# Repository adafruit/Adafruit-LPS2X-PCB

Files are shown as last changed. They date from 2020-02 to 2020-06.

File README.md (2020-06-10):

## Adafruit LPS2X family of absolute pressure sensors PCB

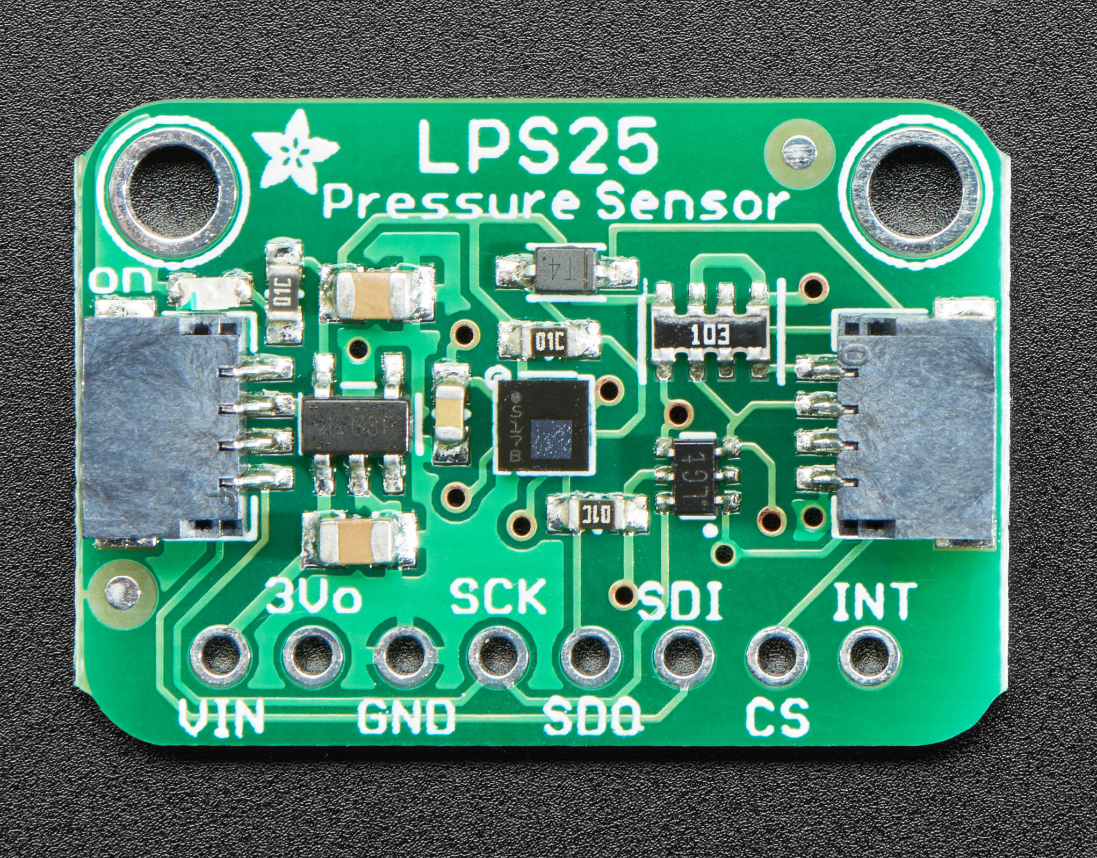
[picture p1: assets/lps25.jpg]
<a href="http://www.adafruit.com/products/4530">
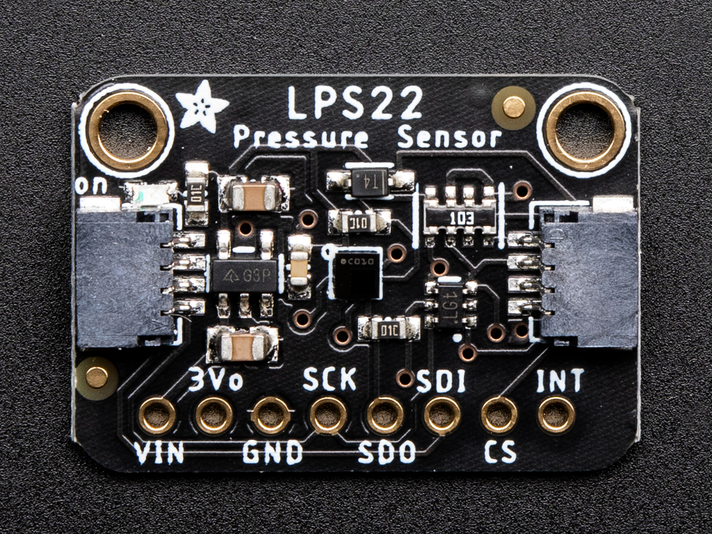
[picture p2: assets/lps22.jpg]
<a href="http://www.adafruit.com/products/4633">
  
Click here to purchase one from the Adafruit shop</a>

PCB files for the Adafruit LPS2X family of absolute pressure sensors. 

Format is EagleCAD schematic and board layout
* https://www.adafruit.com/product/4530
* http://www.adafruit.com/products/4633

### Description

We live on a planet with an atmosphere, a big ocean of gaseous air that keeps everything alive - and that atmosphere is constantly bouncing off of us, exerting air pressure on everything around us. But, how much air is in the atmosphere, bearing down on us?
Absolute pressure sensors  like the **ST LPS22HB** or **ST LPS25HB** can quickly and easily measure this air pressure, useful when you want to know about the weather (are we in a low pressure or high pressure system?) or to determine altitude, as the air thins out the higher we get above sea level. For example, at sea level, the official pressure level is **1013.25 hPa**. You can use these sensors to measure the current pressure where you are right now, to compare.

The LPS25 has a wide measurement range of **260-1260** hPa with 24-bit pressure data measurements that can be read up to **25 times a second (Hz)**, you can be confident that you always have an up to date and precise measurement. The LPS22 has the same measurement range but offers additional measurement rates of **50 and 75Hz**. They’re pretty dang accurate too, with the ability to measure within **0.2 hPa** after calibration (± 1 hPa before calibration).
### License

Adafruit invests time and resources providing this open source design, please support Adafruit and open-source hardware by purchasing products from [Adafruit](https://www.adafruit.com)!

Designed by Limor Fried/Ladyada for Adafruit Industries.

Creative Commons Attribution/Share-Alike, all text above must be included in any redistribution. 
See license.txt for additional details.

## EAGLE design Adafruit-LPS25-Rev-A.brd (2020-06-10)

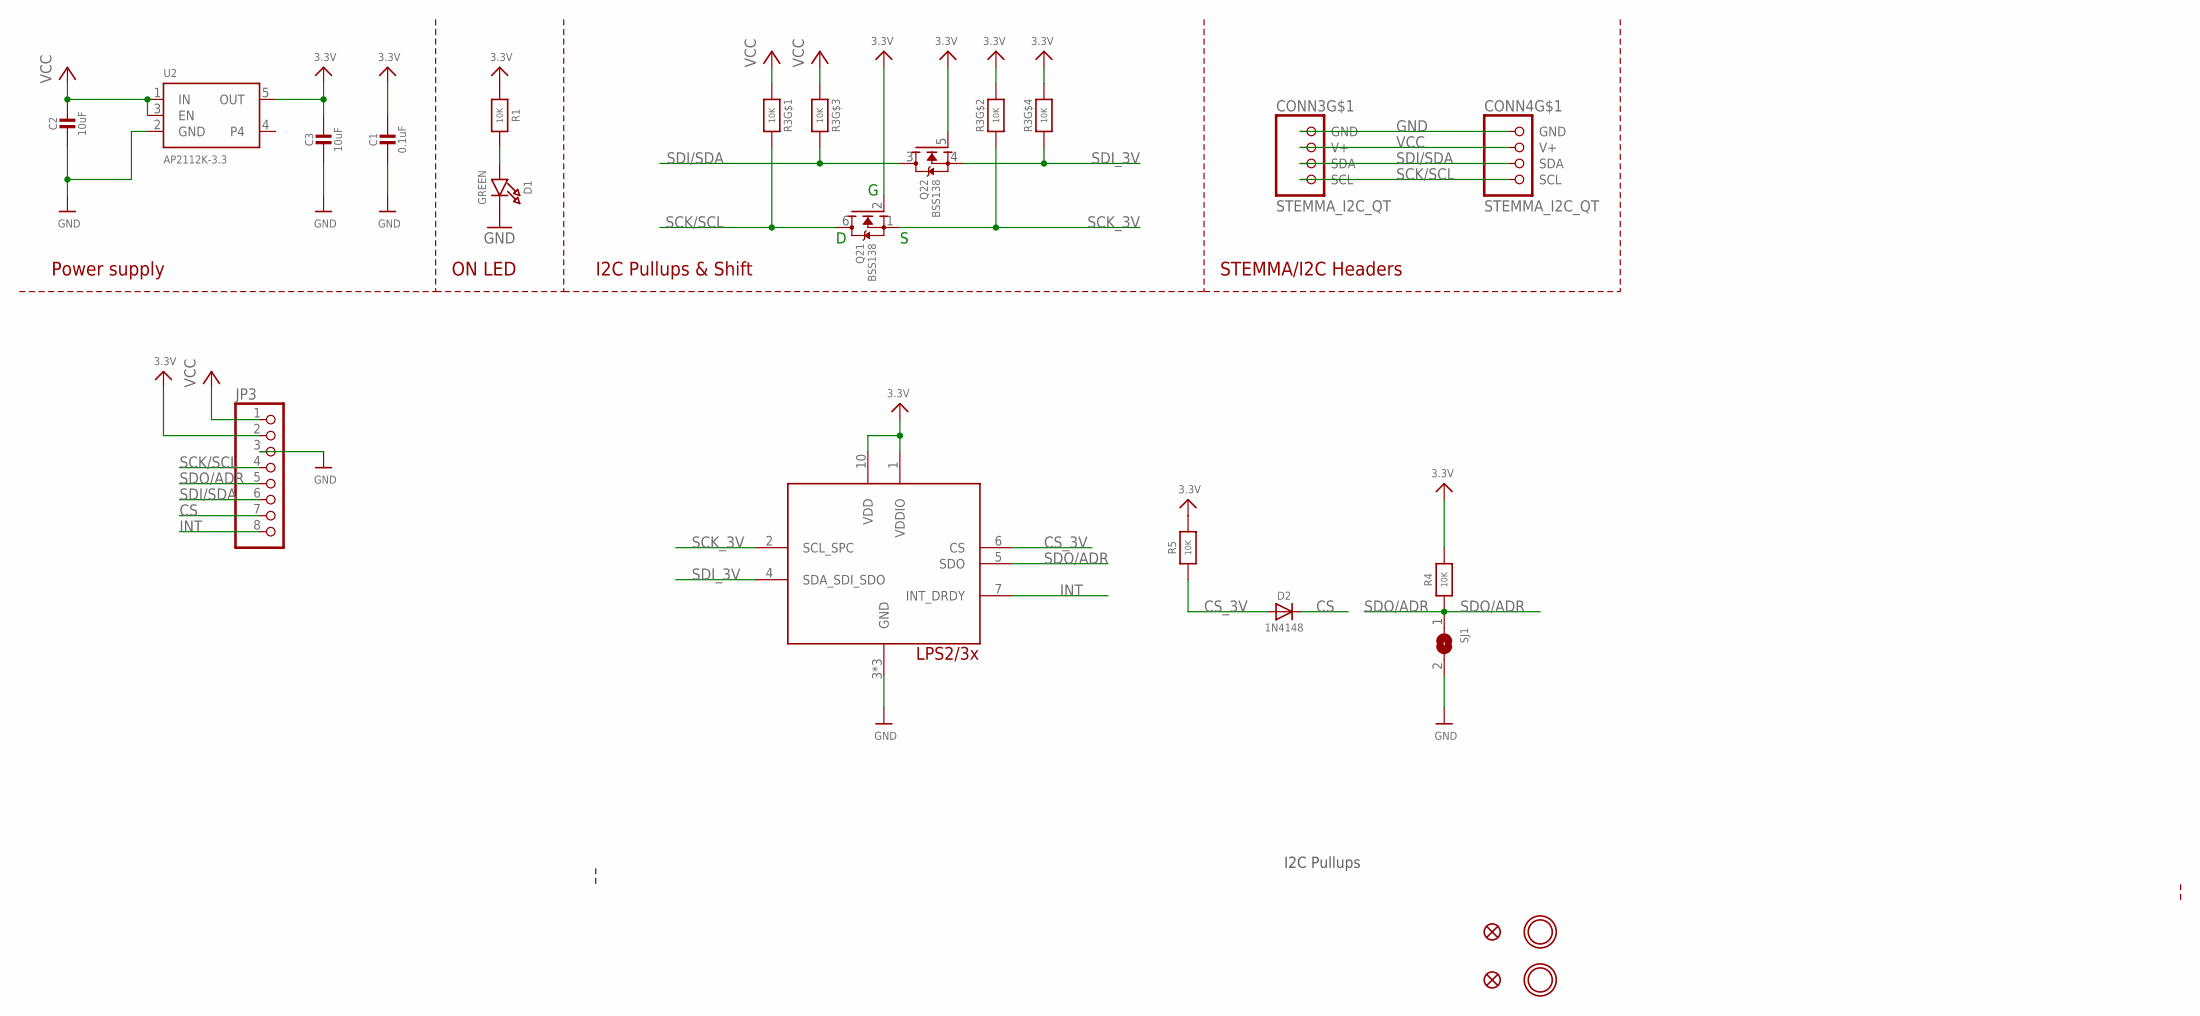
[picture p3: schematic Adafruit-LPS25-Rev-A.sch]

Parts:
C1: 0.1uF; 0603-NO
C2, C3: 10uF; 0805-NO
CONN3, CONN4: STEMMA_I2C_QT; JST_SH4
D1: GREEN; CHIPLED_0603_NOOUTLINE
D2: 1N4148; SOD-323
FID3, FID4: FIDUCIAL_1MM
JP3: HEADER-1X8ROUND; 1X08_ROUND
Q2: BSS138; SOT363
R1, R4, R5: 10K; 0603-NO
R3: 10K; RESPACK_4X0603
SJ1: SOLDERJUMPER; SOLDERJUMPER_ARROW_NOPASTE
U2: AP2112K-3.3; SOT23-5
U$1, U$17: MOUNTINGHOLE2.5; MOUNTINGHOLE_2.5_PLATED
U$2: LPS2X_LPS25; HLGA-10L

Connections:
3.3V: C1.1, C3.1, JP3.2, Q2.2 (G), Q2.5 (G), R1.1, R3.2 (1), R3.4 (1), R4.2, R5.2, U2.5 (OUT), U$2.1 (VDDIO), U$2.10 (VDD)
CS: D2.C, JP3.7
CS_3V: D2.A, R5.1, U$2.6 (CS)
GND: C1.2, C2.2, C3.2, CONN3.1 (GND), CONN4.1 (GND), D1.C, JP3.3, SJ1.2, U2.2 (GND), U$2.3 (GND), U$2.8 (GND), U$2.9 (GND)
INT: JP3.8, U$2.7 (INT_DRDY)
unnamed: D1.A, R1.2
SCK/SCL: CONN3.4 (SCL), CONN4.4 (SCL), JP3.4, Q2.6 (D), R3.8 (2)
SCK_3V: Q2.1 (S), R3.7 (2), U$2.2 (SCL_SPC)
SDI/SDA: CONN3.3 (SDA), CONN4.3 (SDA), JP3.6, Q2.3 (D), R3.6 (2)
SDI_3V: Q2.4 (S), R3.5 (2), U$2.4 (SDA_SDI_SDO)
SDO/ADR: JP3.5, R4.1, SJ1.1, U$2.5 (SDO)
VCC: C2.1, CONN3.2 (V+), CONN4.2 (V+), JP3.1, R3.1, R3.3 (1), U2.1 (IN), U2.3 (EN)

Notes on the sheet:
I2C Pullups & Shift
STEMMA/I2C Headers
ON LED
Power supply
I2C Pullups

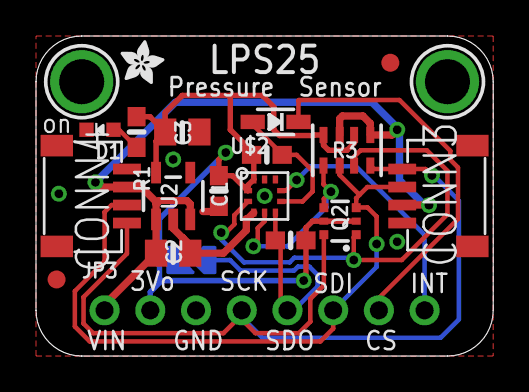
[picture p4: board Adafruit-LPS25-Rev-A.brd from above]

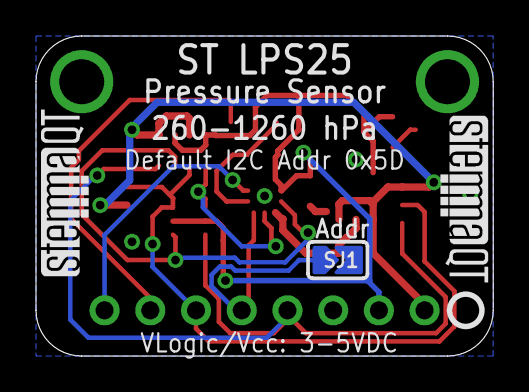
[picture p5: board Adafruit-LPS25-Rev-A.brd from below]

Board: 2 copper layers, 25.4 x 17.8 mm, 24 parts (4 on the bottom side), 12 nets.

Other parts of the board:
U$4: ADAFRUIT_2.5MM
U$25: PCBFEAT-REV-040
U$30, U$31: STEMMAQT

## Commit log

2020-02-24 initial comit
    [Adafruit-LPS2X.brd, Adafruit-LPS2X.sch]
2020-06-10 adding LPS22
    [Adafruit-LPS22-Rev-A.brd, Adafruit-LPS22-Rev-A.sch, Adafruit-LPS25-Rev-A.brd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]

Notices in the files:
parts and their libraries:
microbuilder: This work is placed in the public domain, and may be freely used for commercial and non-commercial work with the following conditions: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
